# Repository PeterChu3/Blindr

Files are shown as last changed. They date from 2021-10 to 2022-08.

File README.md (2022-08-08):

# Blindr

## Background

Blindr blinds

Georgia Tech CS 3651 Prototyping Intelligent Appliances

Throughout the semester, we learn how to use microcontrollers and sensors to sense and react to the world around us. Near the end of the semester, we apply what we learned throughout the semester to make an intelligent device that senses and reacts to the real world.

## Explanation

#### Hardware

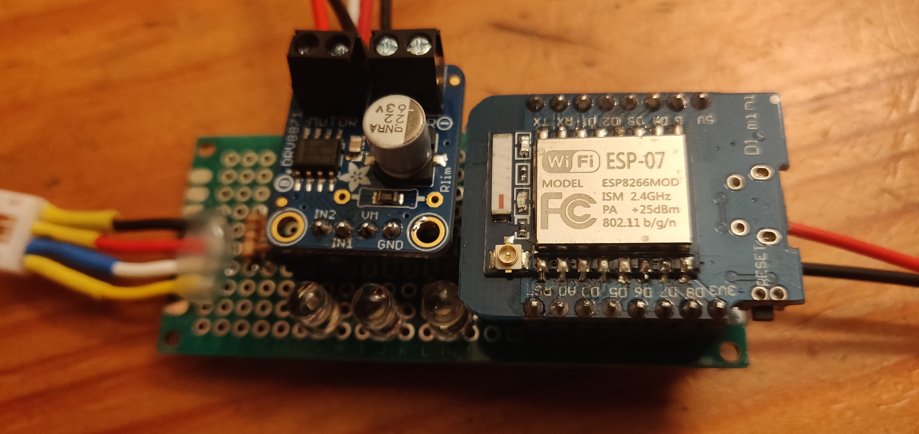
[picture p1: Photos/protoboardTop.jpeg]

For this project, my team Sam Roquitte and Peter Chu came up with the idea of motorizing blinds overlooking Midtown Atlanta in the CS3651 classroom. To achieve this we use a D1 mini microcontroller with ESP8266.

The motor driver is an H-bridge breakout to allow the motor to be controlled from the D1 mini.

To display the state of the blinds, we used LEDs to show the intended position of the blinds.

To sense the world we use a BMP280 to obtain temperature and pressure. However, we used I2C so any future I2C sensor would be able to easily integrate into the system in hardware.

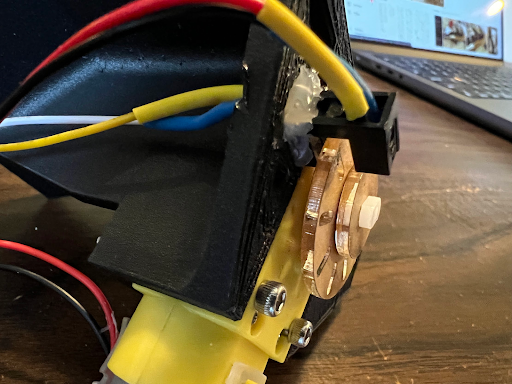
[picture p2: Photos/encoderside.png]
encoder side


The motor is a brushed motor that was plentiful in the classroom. We based our design on the shape of the motor.

To prevent a stall condition of the motor, we designed a rotary encoder from an optical encoder that detects the rotation distance the motor has rotated from the start of the request.

#### Software

The software was coded using the Arduino environment. We used libraries to host a REST server on the D1 Mini.

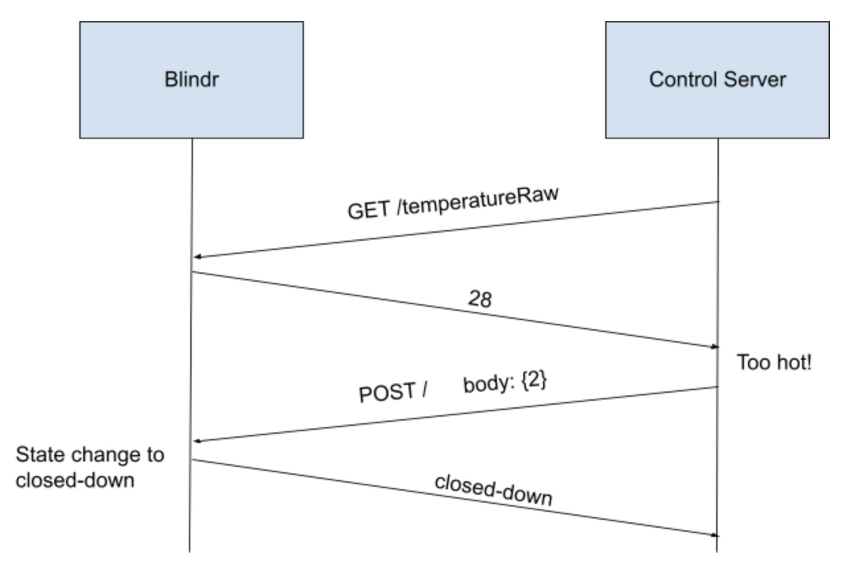
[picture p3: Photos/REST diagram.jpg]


Above is a system paradigm to illustrate how requests are handled and replied to.

We also used a state machine to make sure that all of the different states and transitions are handled and have actions.

[More details of Blindr are available in Final Documentation](https://github.com/PeterChu3/Blindr/blob/main/Docs/Final%20Documentation.pdf)

## Github folders

Folders in this repo:

CAD - Contains all of the solidworks files used to create the project

Code - Contains all of the development code for the D1 Mini

Docs - Contains all of the documentation generated for CS 3651.

Photos - Contains photos to illustrate Blindr.

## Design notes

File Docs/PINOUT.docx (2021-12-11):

PINOUT

A0 = Light Sensor

D1 = i2c SCL

D2 = i2c SDA

D4 = Top LED

D5 = Bottom LED

D6 = Motor

D7 = Motor

D8 = Middle LED

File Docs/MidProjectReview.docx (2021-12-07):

Electronics we plan to use

- Solar charger
- 3.7v 2000mah battery
- Brushed Motor
- ESP32

Software libraries

- Micropython
- ESP32 WIFI library
- MQTT (Google Home API)

Progress

- We have been iterating throughout the project with the 3d models of the project
- We added an encoder wheel to the bottom of the motor
  - Code is functional
- Motor mount design is finalized
- Gearing needs to be fine tuned

Difficulties

- We currently have difficulties turning the blinds smoothly because the rod of the blinds does not stay in the same position.
- We think we can remove the rod and twist the blinds mechanisms manually.
- Protype before Thursday.

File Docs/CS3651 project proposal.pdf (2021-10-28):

Sam & Peter

Blindr

For this project we plan to implement an automated way of opening/closing blinds using the cloud. We will use PCB tools and CAD to design a clean way of opening and closing blinds electrically.

Links:
- https://esphome.io/index.html
- https://esphome.io/guides/getting_started_hassio.html
- https://cdn-learn.adafruit.com/downloads/pdf/adafruit-huzzah32-esp32-feather.pdf
- https://www.home-assistant.io/blog/2021/06/16/power-up-your-esp-projects/

Materials:
- Some form of stepper motor & driver
- Encoder if regular motor
- ESP32 based microcontroller - likely a D1 mini
- 3D printed enclosure & some way to attach it to the frame
- Coupling hardware
- Possible 3D print to connect to the wand then some small universal joints
- PCB or proto board
- Buttons/some form of manual control
- Mechanical coupling to blinds mechanism
- Power distribution - one or multiple of the following
- Battery?
- Solar panel?
- Wall wart?
- (Stretch goal) sensors to automatically open/close Grading Scale:
A: Blinds open/close with via WiFi (home assistant or similar) B: Blinds open/close with realistic user focus
C: Blinds open/close mechanically

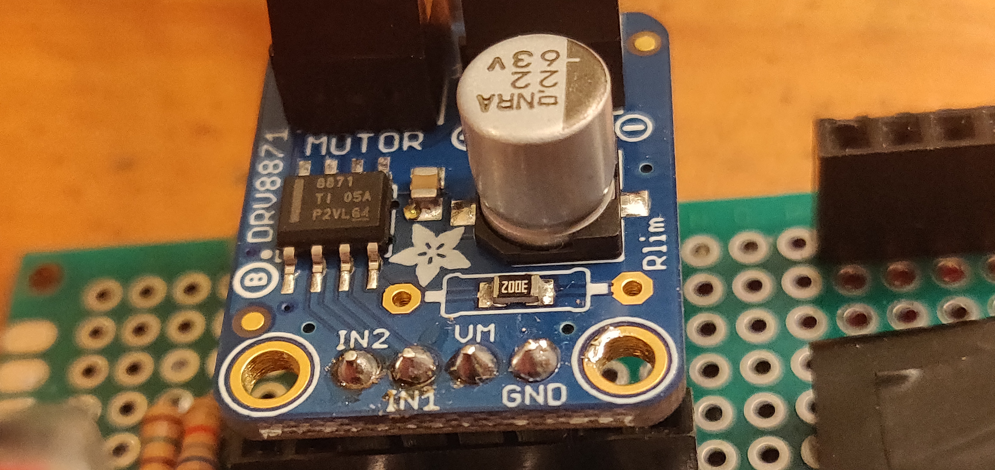
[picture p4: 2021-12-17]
Photos/motorDriver.jpeg

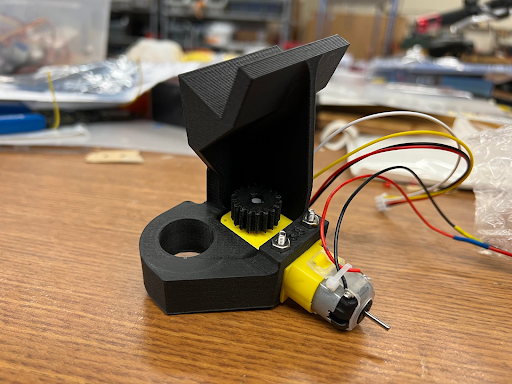
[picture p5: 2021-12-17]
Photos/blindrBracket.png

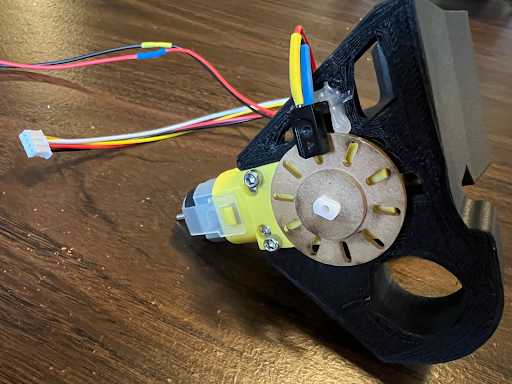
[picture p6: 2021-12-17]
Photos/Encoder.png

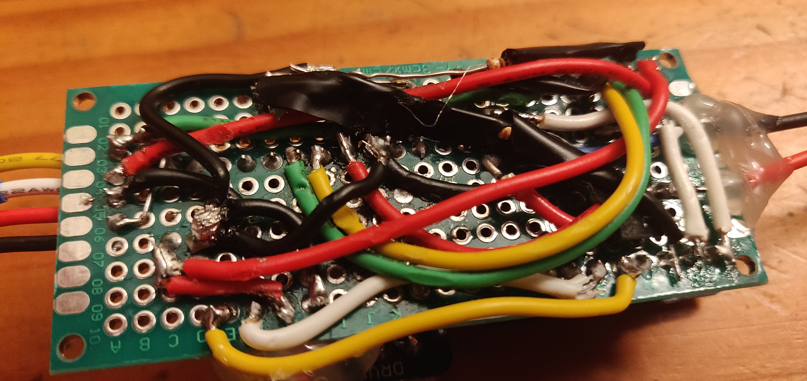
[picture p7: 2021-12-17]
Photos/protoboardBottom.jpeg

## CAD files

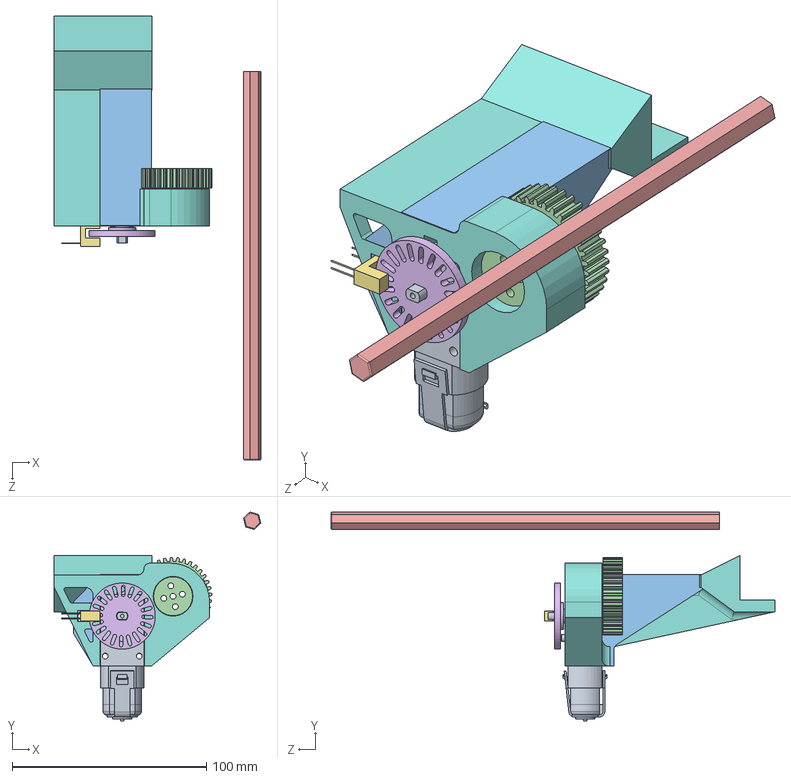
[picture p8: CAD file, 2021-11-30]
CAD/Assem1.SLDASM
106.3 x 107.5 x 228.5 mm
TT Motor
MotorGear
WandGear
BlindWand
MotorEncoderWheel
SharpGP1S53VJ000F
MotorMount_v3

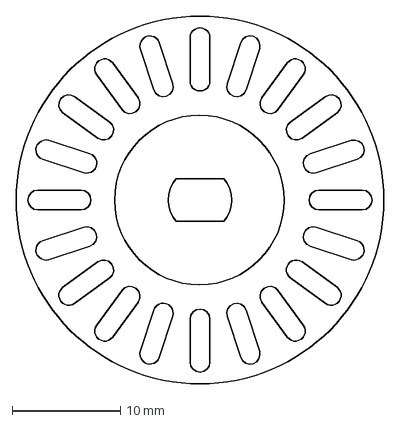
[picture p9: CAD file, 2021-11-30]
CAD/MotorEncoderWheelTOP.dxf
34.0 x 34.0 mm

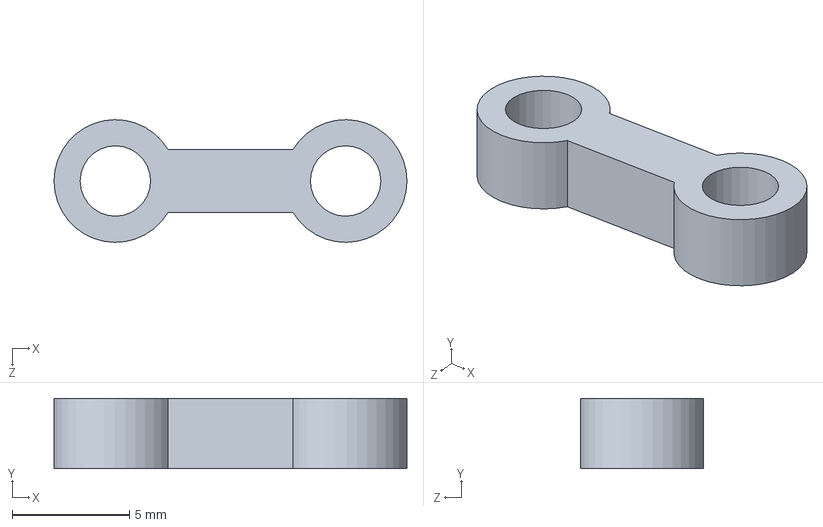
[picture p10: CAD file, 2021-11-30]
CAD/BoneTwister.SLDPRT
15.0 x 3.00 x 5.23 mm

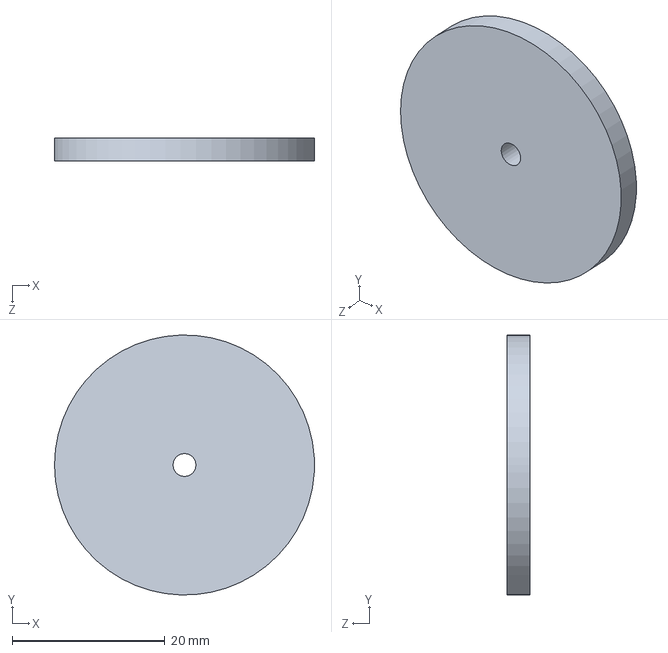
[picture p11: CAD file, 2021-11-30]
CAD/WandGearBottomWheel.SLDPRT
34.0 x 34.0 x 3.00 mm

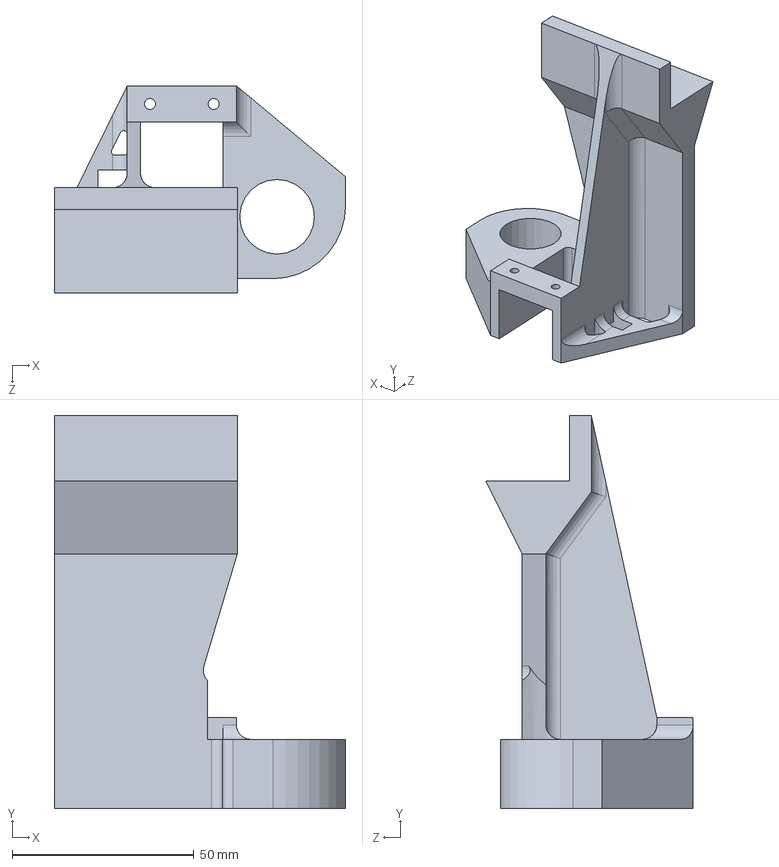
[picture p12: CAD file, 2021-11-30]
CAD/MotorMount_v3.SLDPRT
80.0 x 108.0 x 57.0 mm

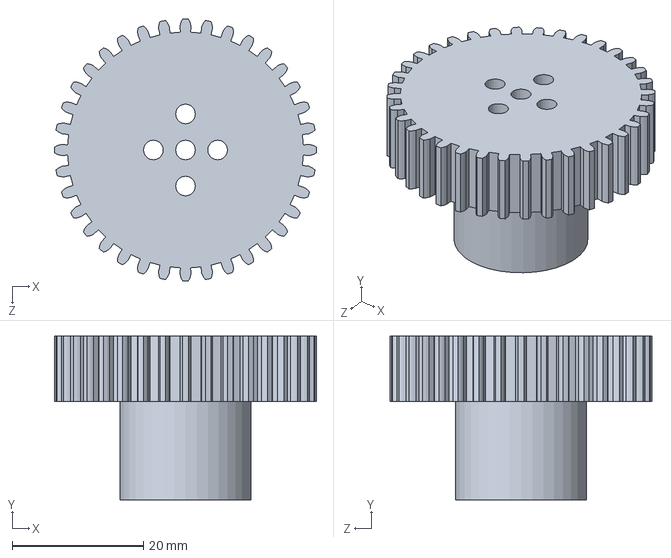
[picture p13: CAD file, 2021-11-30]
CAD/WandGear.SLDPRT
40.0 x 25.0 x 40.0 mm

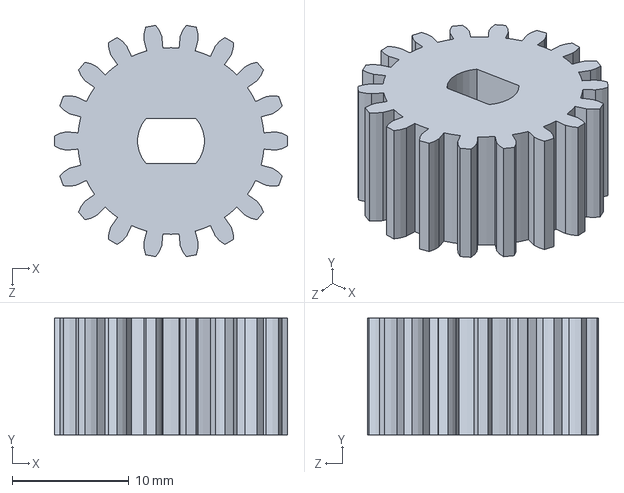
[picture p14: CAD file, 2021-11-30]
CAD/MotorGear.SLDPRT
20.0 x 10.0 x 19.8 mm

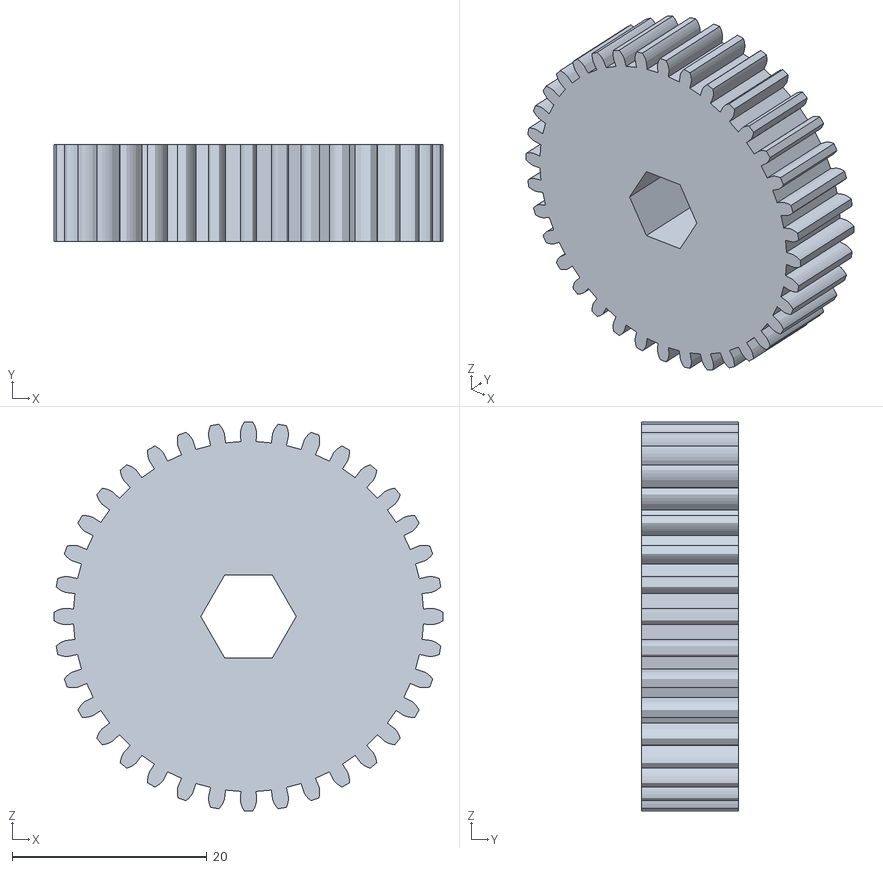
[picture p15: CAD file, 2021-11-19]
CAD/WandGear_v2.STL
40.0 x 10.0 x 40.0

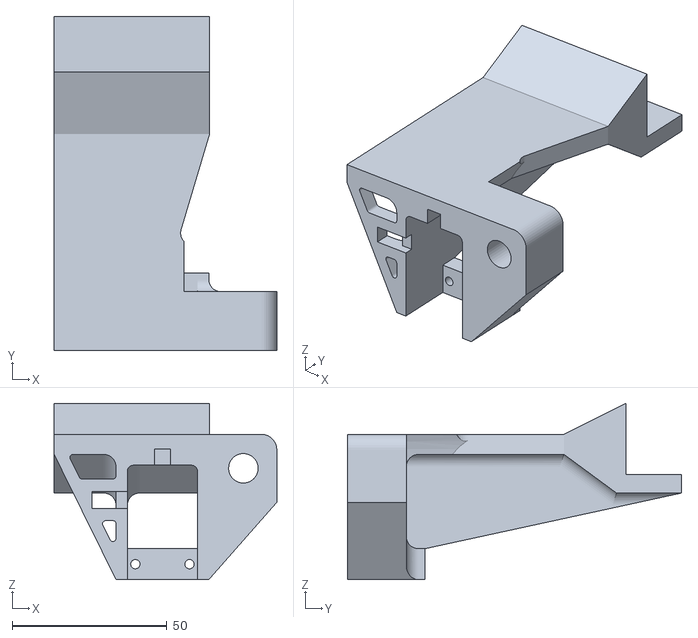
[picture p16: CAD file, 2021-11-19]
CAD/MotorMount_v3.2.STL
72.0 x 108.0 x 57.0

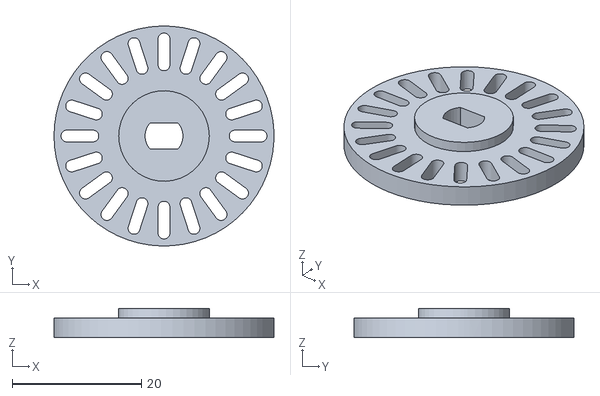
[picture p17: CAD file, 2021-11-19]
CAD/MotorEncoderWheel_v1.STL
34.0 x 34.0 x 4.50

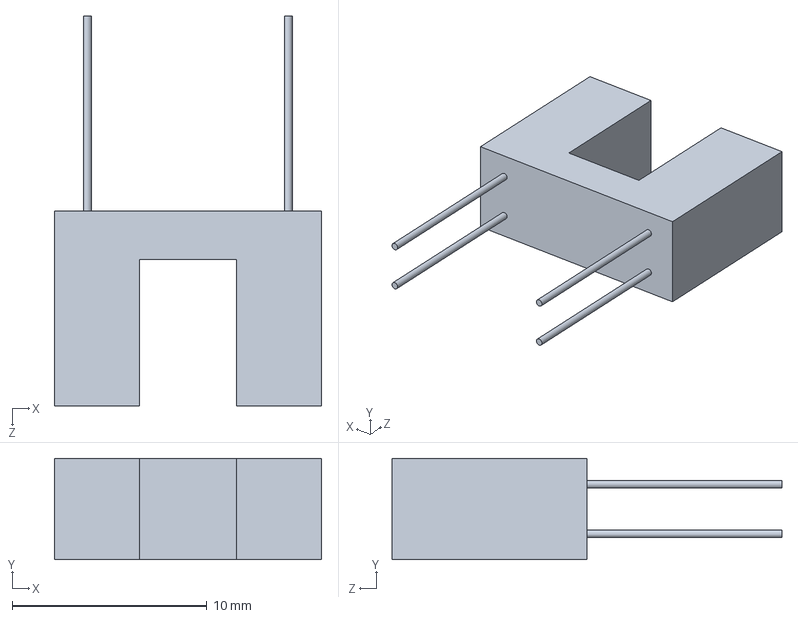
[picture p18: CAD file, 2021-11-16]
CAD/SharpGP1S53VJ000F.SLDPRT
13.7 x 5.20 x 20.0 mm

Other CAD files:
CAD/WandGear_1.0mm.STL
CAD/MotorGear_0.15mm.STL
CAD/WandGear_0.5mm.STL
CAD/MotorGear_0.175mm.STL
CAD/MotorEncoderWheel.SLDPRT
CAD/MotorGear_0.20mm.STL
CAD/WandGear_0.25mm.STL
CAD/BlindWand.SLDPRT
CAD/MotorEncoderWheel.dxf
CAD/MotorMount.SLDPRT
CAD/MotorMount_v1.STL
CAD/MotorMount_v2.SLDPRT
CAD/MotorMount_v2.STL
CAD/MotorMount_v3.1.STL
CAD/MotorMount_v3.STL
CAD/TT Motor.SLDPRT
CAD/WandGear_v1.STL

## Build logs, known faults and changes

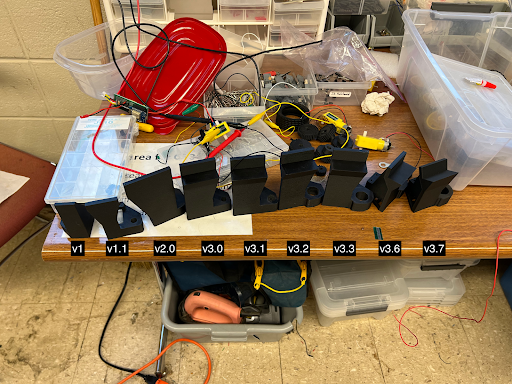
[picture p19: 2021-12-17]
Photos/versionHistory.png

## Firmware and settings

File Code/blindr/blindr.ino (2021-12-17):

#include <ESP8266WebServer.h>

// General config
#define DEBUG 1
// #define BMP280 1

#ifdef BMP280
  #include <Adafruit_BMP280.h>
  #include <Wire.h>
  Adafruit_BMP280 bmp;
#endif

// Wifi config
#define HTTP_REST_PORT 80
const char *ssid = "ssid";
const char *password = "pass";
const String deviceName = "Blindr";
ESP8266WebServer server(HTTP_REST_PORT);

// Blind rotator config
const int GEAR_RATIO = 2;               // Gear ratio of the blind gear to motor (2:1)
const int NUM_ENCODER_HOLES = 10;       // Number of holes in the encoder wheel (10 = 1 rotation)
const double NUM_WAND_ROTATIONS = 1.5;  // Number of wand rotations needed to move from one state to another

// Pinout
#define UP D6
#define DOWN D7
#define LED0 D5
#define LED1 D8
#define LED2 D4

// State constants
#define CLOSED_UP 0
#define OPEN 1
#define CLOSED_DOWN 2

// Can be open (blinds horizontal) or closed (blinds vertical)
// Closed can be up or down (concave up or concave down)
int currentState = OPEN;
int nextState = OPEN;

const int analogInPin = A0;   // Sensor pin
int sensorValue = 0;          // Value read from the sensor
bool wasLow = false;          // Was the sensor low last time we checked?

int ticks = 0;                // Number of ticks since last movement
int tickStop = 0;             // Number of ticks to stop motor at
void setup() {
  #ifdef DEBUG
    Serial.begin(115200);
  #endif
  pinMode(UP, OUTPUT);
  pinMode(DOWN, OUTPUT);
  pinMode(LED0, OUTPUT);
  pinMode(LED1, OUTPUT);
  pinMode(LED2, OUTPUT);

  #ifdef BMP280
    // Initialize BMP280
    if (!bmp.begin(BMP280_ADDRESS_ALT, BMP280_CHIPID)) {
      #ifdef DEBUG
        Serial.println("Could not find a valid BMP280 sensor, check wiring!");
      #endif
      while (1) delay(10);
    }

    bmp.setSampling(Adafruit_BMP280::MODE_NORMAL,     // Operating Mode.
                    Adafruit_BMP280::SAMPLING_X2,     // Temp. oversampling = 2x
                    Adafruit_BMP280::SAMPLING_X16,    // Pressure oversampling = 16x
                    Adafruit_BMP280::FILTER_X16,      // Filtering = 16x
                    Adafruit_BMP280::STANDBY_MS_500); // Standby time = 500ms
  #endif

  // Webserver init
  #ifdef DEBUG
    Serial.println();
    Serial.println();
    Serial.print("Connecting to ");
    Serial.println(ssid);
  #endif

  WiFi.mode(WIFI_STA);
  WiFi.begin(ssid, password);
  while (WiFi.status() != WL_CONNECTED) {
    // Wait a bit and then try again
    delay(500);
    #ifdef DEBUG
        Serial.print(".");
    #endif
  }

  #ifdef DEBUG
    Serial.println("");
    Serial.println("WiFi connected");
  #endif

  // Set routes
  configureRouter();

  // Start the server
  server.begin();

  #ifdef DEBUG
    Serial.println("Server started");
    // Print the IP address
    Serial.print("Use this URL : ");
    Serial.print("http://");
    Serial.print(WiFi.localIP());
    Serial.println("/");
  #endif

}

void loop() {
  server.handleClient();

  // Check if we need to move the blinds/they are moving
  if (currentState != nextState) {
    // Count encoder ticks
    sensorValue = analogRead(analogInPin);
    // #ifdef DEBUG
    //   Serial.print("Sensor value: ");
    //   Serial.println(sensorValue);
    // #endif
    if (sensorValue > 500 && wasLow == true) {
      wasLow = false;
      ticks++;
      // #ifdef DEBUG
      //   Serial.print("Ticks: ");
      //   Serial.println(ticks);
      // #endif
    } else if (sensorValue < 500 && wasLow == false) {
      wasLow = true;
    }
    if (ticks >= tickStop) {
      // Finished transitioning to nextState
      changeLED(nextState, HIGH);
      Brake();
      delay(500);
      Stop();
      currentState = nextState;
    }
  }
}


void handleRoot() {
  server.send(200, "text/plain", "hello from esp8266!\r\n");
}

void configureRouter() {
  server.on("/", HTTP_GET, getState);
  server.on("/", HTTP_POST, changeState);
  #ifdef BMP280
    server.on("/temperature", HTTP_GET, getTemperature);
    server.on("/pressure", HTTP_GET, getPressure);
    // Get raw values (no units) for the server
    server.on("/temperatureRaw", HTTP_GET, getTemperatureRaw);
    server.on("/pressureRaw", HTTP_GET, getPressureRaw);
  #endif
}

// HTTP server helpers
String getStateText() {
  return getStateText(currentState);
}
String getStateText(int state) {
  return state == OPEN ? "open" : state == CLOSED_UP ? "closed-up" : "closed-down";
}

// REST route handlers
void getState() {
  server.send(200, "text/plain", getStateText());
}
void changeState() {
  String post_body = server.arg("plain");
  // Ensure the body is correct
  if (post_body != "0" && post_body != "1" && post_body != "2") {
    #ifdef DEBUG
      Serial.print("Invalid state ");
      Serial.print("'");
      Serial.print(post_body);
      Serial.println("'");
    #endif
    server.send(400, "text/plain", "Invalid state");
    return;
  }
  int newState = post_body.toInt();
  nextState = newState;
  #ifdef DEBUG
    Serial.print(getStateText(currentState));
    Serial.print(" -> ");
    Serial.println(getStateText(newState));
  #endif
  changeLED(currentState, LOW);
  moveTo(newState);
  String res = getStateText(currentState) + " -> " + getStateText(newState);
  server.send(200, "text/html", res);
}
#ifdef BMP280
  void getTemperature() {
    server.send(200, "text/plain", String(bmp.readTemperature()) + "°C");
  }
  void getPressure() {
    server.send(200, "text/plain", String(bmp.readPressure()) + "Pa");
  }
  void getTemperatureRaw() {
    server.send(200, "text/plain", String(bmp.readTemperature()));
  }
  void getPressureRaw() {
    server.send(200, "text/plain", String(bmp.readPressure()));
  }
#endif

// LED helpers
void changeLED(int state, bool ison) {
  if (state == 0) {
    digitalWrite(LED0, ison);
  } else if (state == 1) {
    digitalWrite(LED1, ison);
  } else {
    digitalWrite(LED2, ison);
  }
}

// Motor control helpers
void moveTo(int newState) {
  if (newState == currentState) {
    return;
  }
  int numRotations = currentState - newState;
  bool isForward = numRotations > 0;
  // Rotations always positive now that we have determined direction
  if (numRotations < 0) {
    numRotations = -numRotations;
  }
  // Start transition to newState
  ticks = 0;
  tickStop = numRotations * NUM_ENCODER_HOLES * GEAR_RATIO * NUM_WAND_ROTATIONS;
  #ifdef DEBUG
    Serial.print("ticks = ");
    Serial.print(ticks);
    Serial.print(" | tickStop = ");
    Serial.println(tickStop);
  #endif
  if (isForward) {
    Forward();
  } else {
    Backward();
  }
}
void Forward() {
  digitalWrite(UP, HIGH);
  digitalWrite(DOWN, LOW);
}
void Backward() {
  digitalWrite(UP, LOW);
  digitalWrite(DOWN, HIGH);
}
void Brake() {
  digitalWrite(UP, HIGH);
  digitalWrite(DOWN, HIGH);
}
void Stop() {
  digitalWrite(UP, LOW);
  digitalWrite(DOWN, LOW);
}

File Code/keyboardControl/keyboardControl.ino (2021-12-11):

#include <HCSR04.h>
#define UP D6
#define DOWN D7

#define LED1 D5
#define LED2 D4
#define LED3 D8

int ledState = LOW;

unsigned long previousMillis = 0;

void setup() {
  Serial.begin(9600);
  while (!Serial) {
    ; // wait for serial port to connect. Needed for native USB
  }
  pinMode(UP, OUTPUT);
  pinMode(DOWN, OUTPUT);
//  pinMode(LED1, OUTPUT);
//  pinMode(LED2, OUTPUT);
//  pinMode(LED3, OUTPUT);


}

void loop() {
  while (Serial.available() > 0)
  {

    //Read the next available byte in the serial receive buffer
    char inByte = Serial.read();
    if (inByte == 'u') {
      Serial.println("up");
      Forward();
    } else if (inByte == 'd') {
      Serial.println("down");
      Backward();
    } else if (inByte == 's') {
      Serial.println("stop");
      Stop();
    }
  }
  unsigned long currentMillis = millis();

  if (currentMillis - previousMillis >= 1000) {
    // save the last time you blinked the LED
    previousMillis = currentMillis;

    // if the LED is off turn it on and vice-versa:
    if (ledState == LOW) {
      ledState = HIGH;
    } else {
      ledState = LOW;
    }

    // set the LED with the ledState of the variable:
    digitalWrite(LED1, ledState);
    digitalWrite(LED2, ledState);
    digitalWrite(LED3, ledState);
  }
}
void Forward() {
  digitalWrite(UP, HIGH);
  digitalWrite(DOWN, LOW);
}
void Backward() {
  digitalWrite(UP, LOW);
  digitalWrite(DOWN, HIGH);
}
void Stop() {
  digitalWrite(UP, LOW);
  digitalWrite(DOWN, LOW);
}

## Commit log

2021-11-03 Start CAD
    [Assem1.SLDASM, BlindWand.SLDPRT, MotorGear.SLDPRT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]
2021-11-10 CAD - motor mount and asm
    [Assem1.SLDASM, BlindWand.SLDPRT, MotorGear.SLDPRT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]
2021-11-16 Motor mount V2
    [Assem1.SLDASM, MotorGear.SLDPRT, MotorMount.SLDPRT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]
2021-11-16 Update main asm to include wand
    [Assem1.SLDASM]
2021-11-16 Update motor mount and add encoder stuff
    [Assem1.SLDASM, MotorEncoderWheel.SLDPRT, MotorMount_v2.SLDPRT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]
2021-11-19 Update motor mount
    [Assem1.SLDASM, MotorMount_v3.SLDPRT]
2021-11-19 Add stl models
    [MotorEncoderWheel_v1.STL, MotorGear_0.15mm.STL, MotorGear_0.175mm.STL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]
2021-11-23 added dxf for lasercutting
    [MotorEncoderWheel.dxf]
2021-11-23 Added second part to lasercut
    [MotorEncoderWheelTOP.dxf]
2021-11-30 Update cad
    [Assem1.SLDASM, BoneTwister.SLDPRT, MotorGear.SLDPRT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]
2021-12-11 Updated code with brake function to stop spinning motor
